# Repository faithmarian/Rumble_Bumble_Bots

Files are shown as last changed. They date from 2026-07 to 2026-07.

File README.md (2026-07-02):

# Rumble Bumble Bots

Team repository for the MTRN3100 micromouse project.

## Repository Layout

- `arduino/` - Arduino Nano sketches for sensor diagnostics, PID/IMU driving, and Week 8 driving tasks.
- `webots_week4/` - Webots worlds, robot protos, C# controller source, and map drawing utilities.
- `print/` - CAD and printable chassis/support files.
- `project/` - Project schematic images used by the team.

## Arduino Sketches

The Week 8 sketches share pin mappings and helper code in `arduino/week8_common/MTRNWeek8Common.hpp`.

Install these Arduino libraries before uploading:

- `MPU6050_light`
- `VL6180X` by Pololu

The OLED code uses `Wire` directly and does not require an extra OLED library.

## Webots Controllers

The Webots controllers are C# projects. Generated `bin/`, `obj/`, executable, DLL, and PDB outputs are intentionally ignored so the repository stays source-focused.

## Publish Notes

This repository intentionally excludes local Codex state, lecture/lab handouts, downloaded reference repositories, course PDFs, build outputs, logs, archives, and environment/secret files.

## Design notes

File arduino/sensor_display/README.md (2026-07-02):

# Sensor Display Diagnostic

Open `sensor_display.ino` in Arduino IDE and upload it to the Arduino Nano.

## What It Shows

- MPU6050 angles: X, Y, Z in degrees
- VL6180X distances: left, front, right in millimetres
- Serial Monitor debug at `115200` baud, including an I2C scan

## Libraries

Install these from Arduino Library Manager:

- `MPU6050_light` by rfetick
- `VL6180X` by Pololu

The OLED code is driven directly through `Wire`, so it does not need `U8g2`,
`Adafruit_SSD1306`, or `SSD1306Ascii`.

## Course PCB Wiring From The Schematic

- OLED SSD1306: `A4 SDA`, `A5 SCL`, `+5`, `GND`
- MPU6050: `A4 SDA`, `A5 SCL`, `+5`, `GND`
- Left VL6180X GPIO0/XSHUT: `A0`
- Front VL6180X GPIO0/XSHUT: `A2`
- Right VL6180X GPIO0/XSHUT: `A1`

The three VL6180X sensors all start at I2C address `0x29`, so the sketch turns all of them off first, then enables them one by one and changes their addresses to:

- Left: `0x54`
- Front: `0x56`
- Right: `0x55`

## If The OLED Is Still Dark

1. Check the OLED is plugged into `J13` in the right orientation.
2. Check the board has `+5V` and `GND`; the course OLED is powered from `+5V`.
3. Open Serial Monitor at `115200` and read the I2C scan.
4. If the scan does not show an OLED address, usually `0x3C`, the OLED is not electrically connected.
5. If the scan shows `0x3C` but the screen is dark, the module may not be SSD1306-compatible even though the 2025 schematic labels it as SSD1306.

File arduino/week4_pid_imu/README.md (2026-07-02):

# Week 4 PID + IMU Arduino Controller

Open `week4_pid_imu.ino` in Arduino IDE and upload to the Arduino Nano.

## What It Does

1. Calibrates the MPU6050 while the robot is stationary.
2. Drives forward 200 mm using encoder distance feedback.
3. Uses MPU6050 yaw feedback to keep the robot straight.
4. Performs four 90 degree left turns.
5. Performs four 90 degree right turns.

## Pin Mapping

This follows the UNSW MDI controller PCB and the working `micromouse1.2` code:

- Left motor/MOT1: PWM `D11`, DIR `D12`
- Right motor/MOT2: PWM `D9`, DIR `D10`
- Left encoder: A `D2`, B `D7`
- Right encoder: A `D3`, B `D8`
- MPU6050: SDA `A4`, SCL `A5`

## First Checks

- The motor convention now matches `micromouse1.2`: straight motion sends `motor1=+pwm`, `motor2=+pwm`.
- Right motor inversion is handled inside `setMotorCommand()` because motor 2 is physically mounted opposite.
- If straight motion spins in place, check the `if (motorNumber == 2) command = -command;` line.
- If a 200 mm command does not travel 200 mm, tune `WHEEL_RADIUS_MM` or `ENCODER_COUNTS_PER_REV`.
- If turning is the wrong direction, swap the signs in `setWheelPwm(turn, -turn)` inside `turnRelativeDeg`.

## Main Tuning Constants

- Straight distance: `DRIVE_DISTANCE_MM`
- Wheel radius: `WHEEL_RADIUS_MM`
- Axle track: `AXLE_TRACK_MM`
- Encoder CPR: `ENCODER_COUNTS_PER_REV`
- Straight PID: `distancePid`, `driveYawPid`, `wheelSyncPid`
- Turn PID: `turnYawPid`
- PWM caps: `DRIVE_PWM_MAX`, `TURN_PWM_MAX`

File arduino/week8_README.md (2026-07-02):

# Week 8 Arduino Sketches

These four sketches match the Week 8 simple driving assessment tasks.

## Common Hardware Assumptions

All sketches use the course PCB schematic:

- Left motor: PWM `D11`, DIR `D12`
- Right motor: PWM `D9`, DIR `D10`
- Left encoder: A `D2`, B `D7`
- Right encoder: A `D3`, B `D8`
- MPU6050: `A4 SDA`, `A5 SCL`
- OLED SSD1306: `A4 SDA`, `A5 SCL`
- Left VL6180X XSHUT: `A0`, address changed to `0x54`
- Front VL6180X XSHUT: `A2`, address changed to `0x56`
- Right VL6180X XSHUT: `A1`, address changed to `0x55`

The OLED code does not need `U8g2`. It is driven directly using `Wire`.

Install these Arduino libraries:

- `MPU6050_light`
- `VL6180X` by Pololu

## Sketches

- `week8_1_straight_tracking`: Task 3.1, drive straight slightly past the 1 m finish line using IMU heading hold.
- `week8_2_lidar_stop`: Task 3.2, front LiDAR wall following to `100 mm`.
- `week8_3_turning`: Task 3.3, right 90 degrees, then recover after external rotation.
- `week8_4_chaining`: Task 3.4, execute the marking-day command string.

## Values To Tune First

- Straight task: `STRAIGHT_DISTANCE_MM`
- Wall task: `TARGET_WALL_MM`, `WALL_TOL_MM`, PID values inside `trackWallToTarget()`
- Turning task: PID values inside `turnToYaw()` in `week8_common/MTRNWeek8Common.hpp`
- Chaining task: `COMMAND_STRING`, `CELL_DISTANCE_MM`

## OLED Display

Every sketch displays:

- `X/Y/Z`: MPU6050 angles in degrees
- `L/F/R`: left, front, right LiDAR distances in millimetres
- Top row: current task/stage

## Suggested Test Order

1. Upload `week8_1_straight_tracking` and tune straight-line PWM/PID.
2. Upload `week8_3_turning` and tune turn PID.
3. Upload `week8_2_lidar_stop` and tune wall distance control.
4. Upload `week8_4_chaining`, set the real command string, and tune `CELL_DISTANCE_MM`.

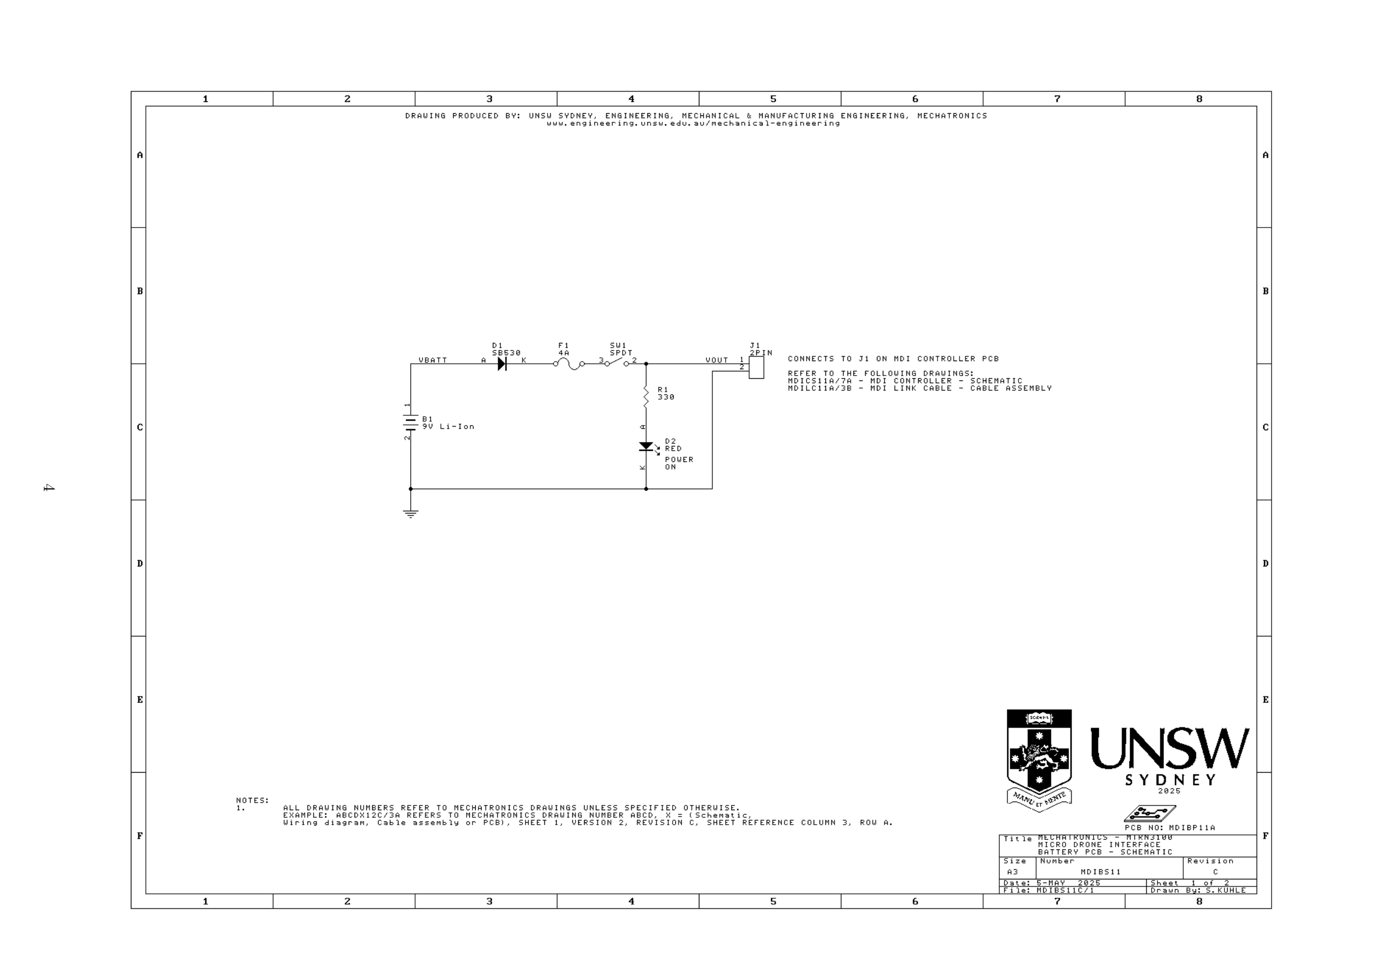
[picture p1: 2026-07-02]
project/kit_schematic-4.png

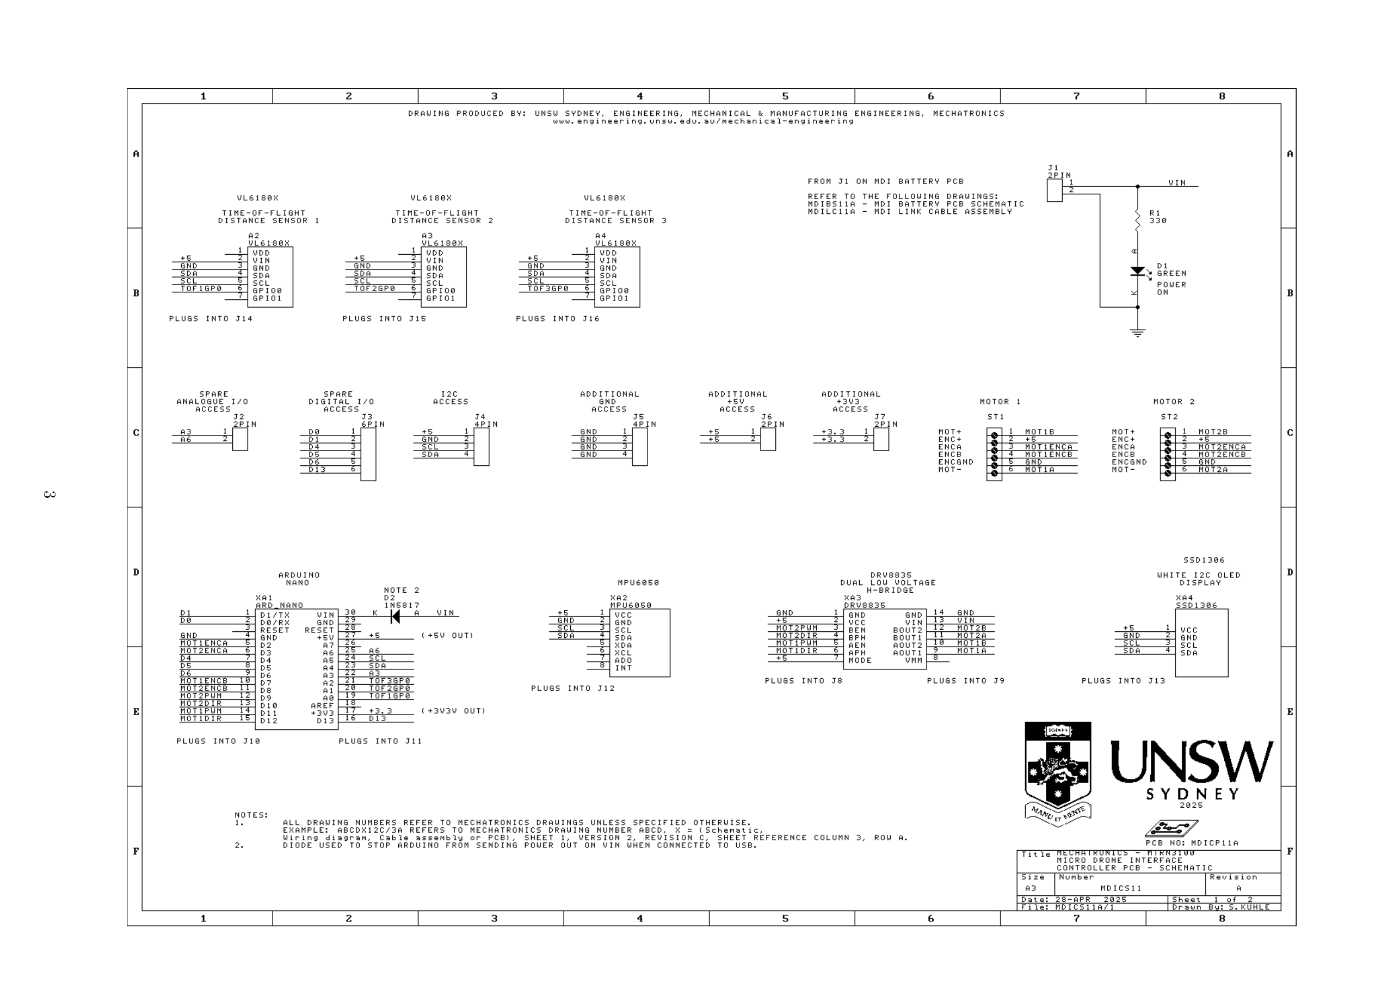
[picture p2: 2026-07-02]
project/kit_schematic-3.png

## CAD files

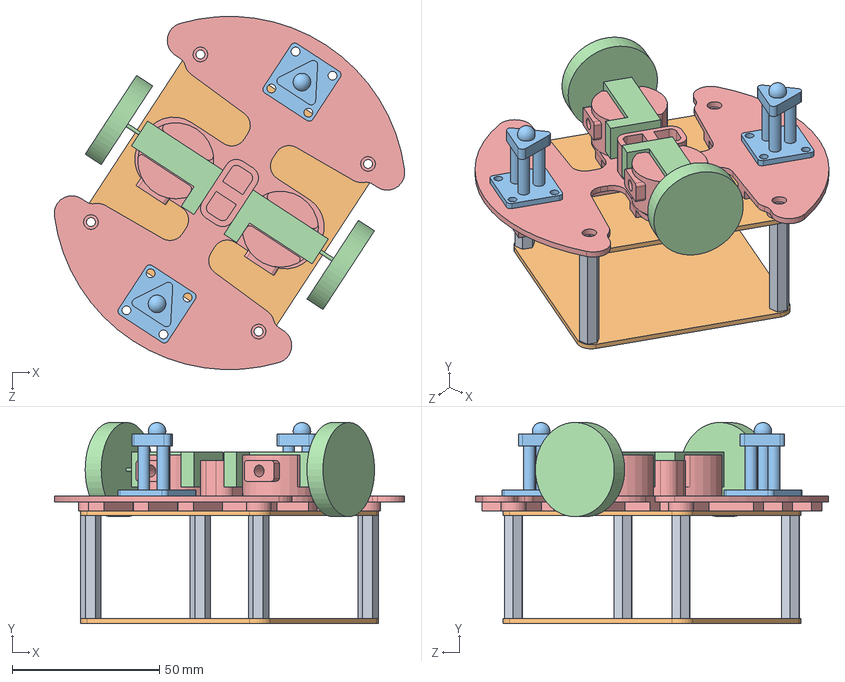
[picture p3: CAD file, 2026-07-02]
print/assume.SLDASM
119.0 x 68.3 x 119.9 mm
chassis
wheel x 2
ball_caster x 2
board x 2
support x 4

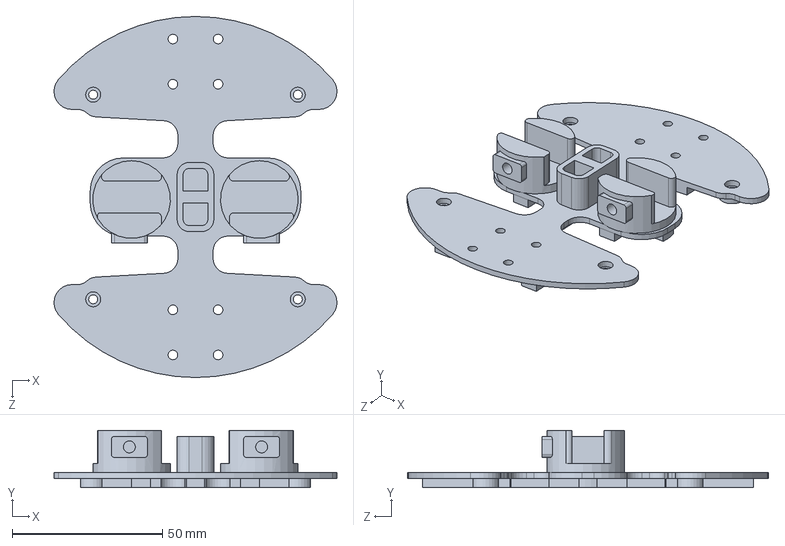
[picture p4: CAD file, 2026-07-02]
print/chassis.SLDPRT
94.1 x 19.0 x 120.0 mm

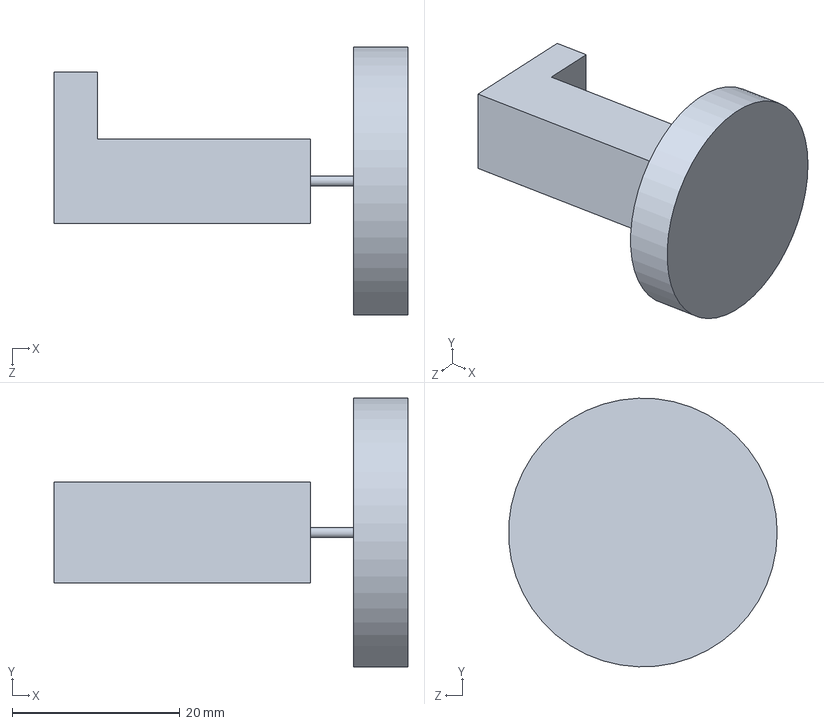
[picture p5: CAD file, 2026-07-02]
print/wheel.SLDPRT
42.2 x 32.0 x 32.0 mm

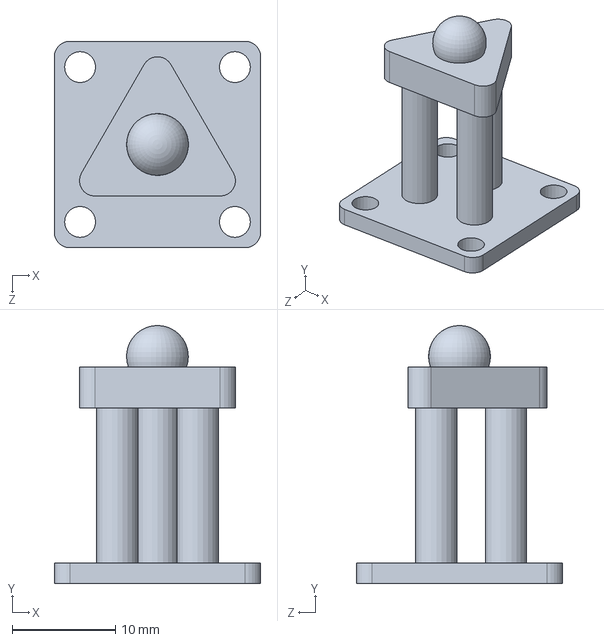
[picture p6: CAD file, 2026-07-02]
print/ball_caster.SLDPRT
20.0 x 25.0 x 20.0 mm

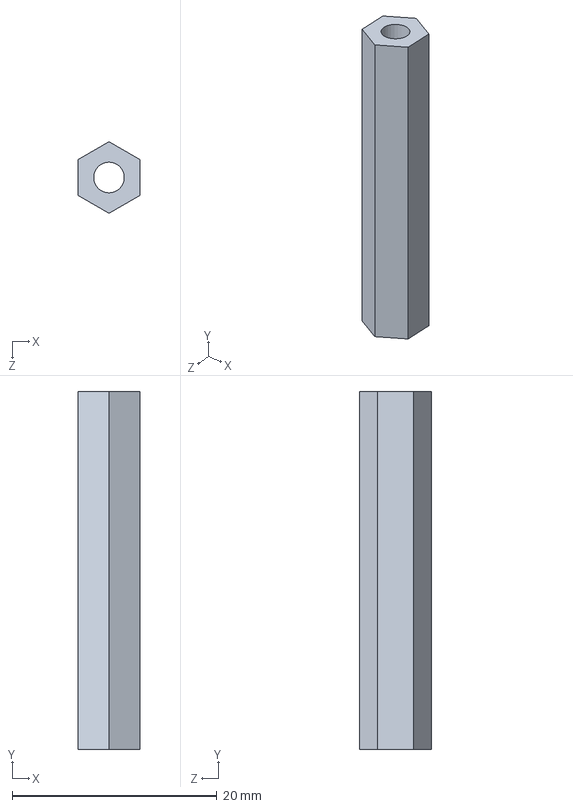
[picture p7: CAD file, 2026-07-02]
print/support.SLDPRT
6.06 x 35.0 x 7.00 mm

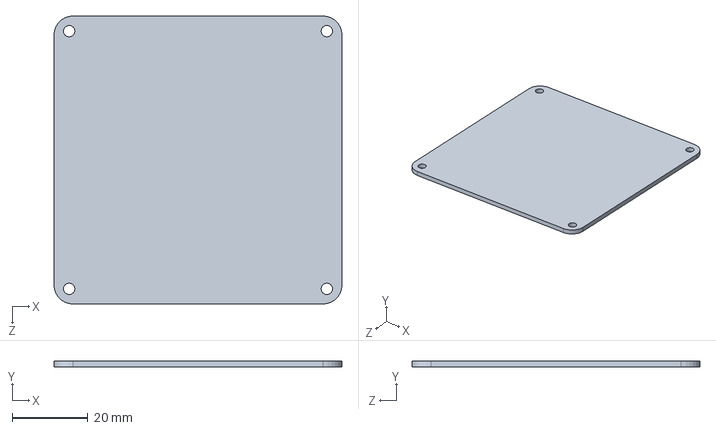
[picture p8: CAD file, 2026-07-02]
print/board.SLDPRT
76.0 x 1.65 x 76.0 mm

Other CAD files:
print/chassis.STL
print/support.STL

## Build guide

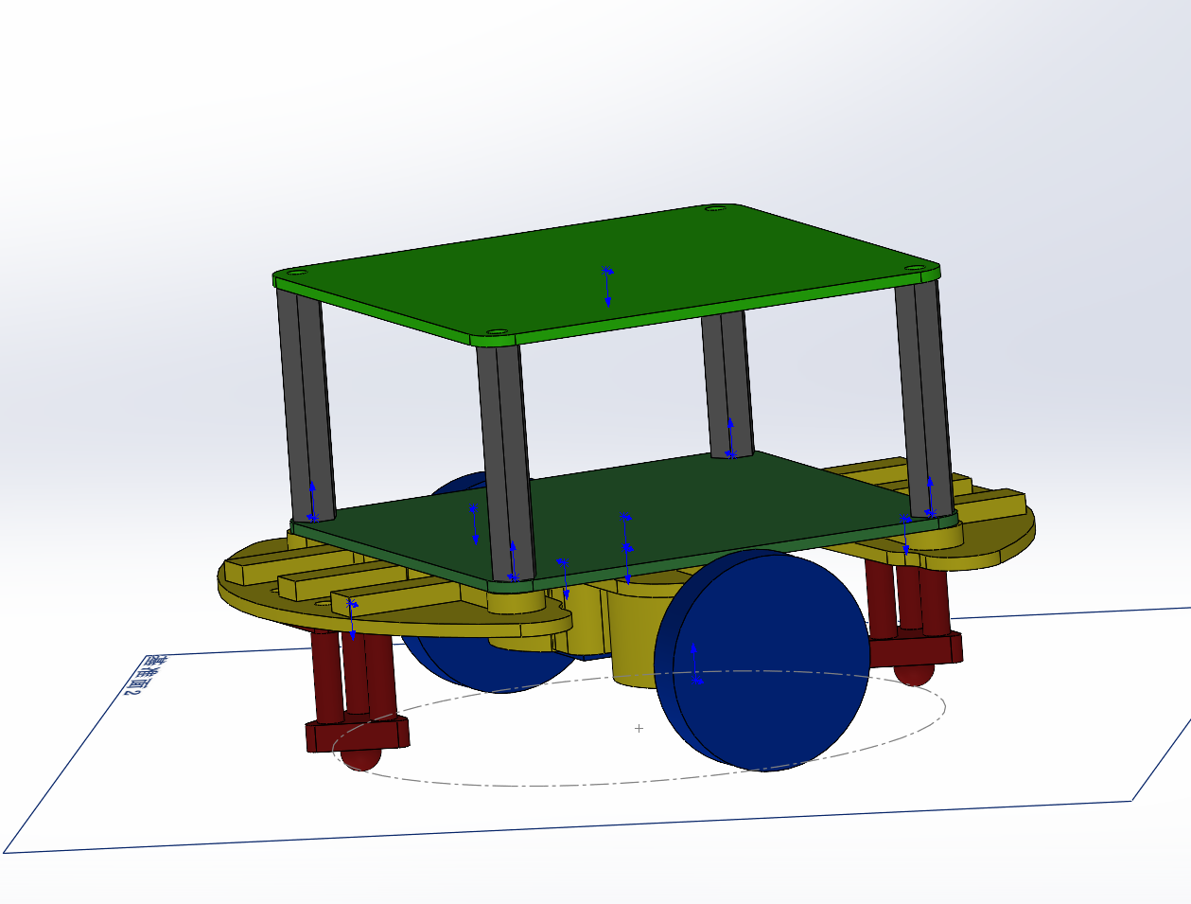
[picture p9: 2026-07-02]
print/2026-06-20 115022.png

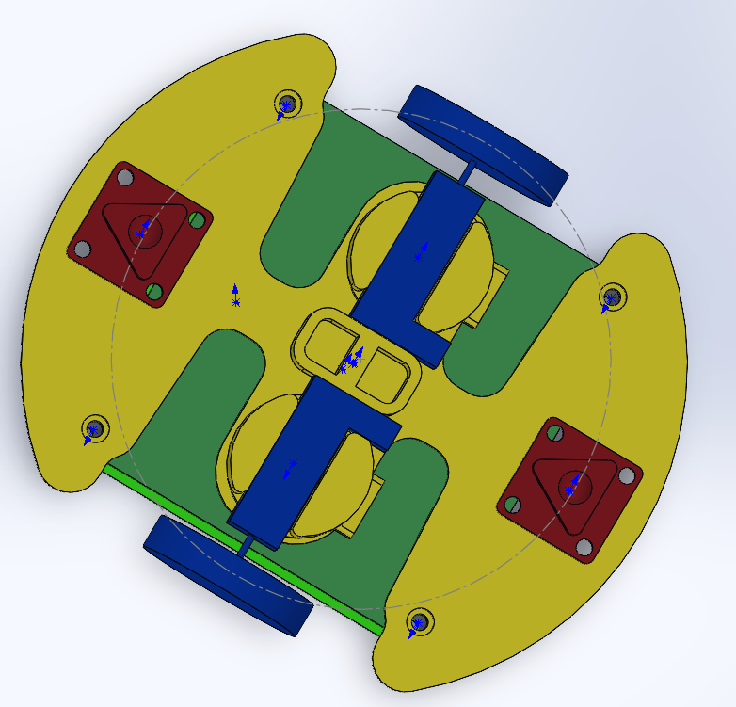
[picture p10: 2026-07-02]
print/2026-06-20 115451.png

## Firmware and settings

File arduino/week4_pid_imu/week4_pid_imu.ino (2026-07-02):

/*
  MTRN3100 Week 4 barebones movement controller.

  Sequence:
    1. Drive forward 200 mm using encoder distance PID.
    2. Hold the initial IMU yaw during the drive using yaw PID.
    3. Turn left 90 deg four times using IMU yaw PID.
    4. Turn right 90 deg four times using IMU yaw PID.

  Hardware mapping follows the UNSW MDI controller PCB and the working
  micromouse1.2 motor/encoder logic:
    Left motor  (MOT1): PWM D11, DIR D12
    Right motor (MOT2): PWM D9,  DIR D10
    Left encoder:  A D2 interrupt, B D7
    Right encoder: A D3 interrupt, B D8
    MPU6050: I2C on A4 SDA, A5 SCL

  Required Arduino library:
    MPU6050_light by rfetick
*/

#include <Arduino.h>
#include <Wire.h>
#include <MPU6050_light.h>

// ------------------------- Pin Map -------------------------
const uint8_t LEFT_ENC_A = 2;
const uint8_t LEFT_ENC_B = 7;
const uint8_t RIGHT_ENC_A = 3;
const uint8_t RIGHT_ENC_B = 8;

const uint8_t LEFT_PWM = 11;
const uint8_t LEFT_DIR = 12;
const uint8_t RIGHT_PWM = 9;
const uint8_t RIGHT_DIR = 10;

// ---------------------- Robot Geometry ---------------------
// These match the working micromouse1.2 code. Numerically this is equivalent
// to the lab04 16 mm / 700 CPR pair, but it preserves the tested convention.
const float WHEEL_RADIUS_MM = 32.0f;
const float AXLE_TRACK_MM = 90.0f;
const float ENCODER_COUNTS_PER_REV = 1400.0f;
const float MM_PER_COUNT = (2.0f * PI * WHEEL_RADIUS_MM) / ENCODER_COUNTS_PER_REV;

const float DRIVE_DISTANCE_MM = 200.0f;
const float TURN_ANGLE_DEG = 90.0f;

// -------------------- Direction Calibration ----------------
// This follows micromouse1.2:
//   motor1.setPWM(+pwm), motor2.setPWM(+pwm) drives straight.
//   motor2 is inverted inside setMotorCommand() because it is mounted opposite.
//   turn left:  motor1 +pwm, motor2 -pwm.
//   turn right: motor1 -pwm, motor2 +pwm.

// Fine trim if one side is mechanically stronger. Keep near 1.0.
const float LEFT_PWM_TRIM = 1.00f;
const float RIGHT_PWM_TRIM = 1.00f;

// ------------------------ PWM Limits -----------------------
const int DRIVE_PWM_MIN = 42;
const int DRIVE_PWM_MAX = 125;
const int TURN_PWM_MIN = 42;
const int TURN_PWM_MAX = 115;
const int CORRECTION_PWM_MAX = 45;

const float DRIVE_DONE_TOL_MM = 2.0f;
const float TURN_DONE_TOL_DEG = 1.5f;
const uint8_t DONE_STABLE_CYCLES = 10;

// -------------------------- PID ----------------------------
struct PID {
  float kp;
  float ki;
  float kd;
  float integralLimit;
  float outputLimit;
  float integral;
  float lastError;
  bool first;

  PID(float p, float i, float d, float iLimit, float oLimit)
      : kp(p), ki(i), kd(d), integralLimit(iLimit), outputLimit(oLimit),
        integral(0.0f), lastError(0.0f), first(true) {}

  void reset() {
    integral = 0.0f;
    lastError = 0.0f;
    first = true;
  }

  float update(float error, float dt) {
    if (dt <= 0.0f) {
      dt = 0.001f;
    }

    integral += error * dt;
    integral = constrain(integral, -integralLimit, integralLimit);

    float derivative = 0.0f;
    if (!first) {
      derivative = (error - lastError) / dt;
    }

    first = false;
    lastError = error;

    float output = kp * error + ki * integral + kd * derivative;
    return constrain(output, -outputLimit, outputLimit);
  }
};

// Distance error is in mm, yaw error is in deg.
PID distancePid(1.15f, 0.00f, 0.10f, 80.0f, DRIVE_PWM_MAX);
PID driveYawPid(2.30f, 0.00f, 0.10f, 45.0f, CORRECTION_PWM_MAX);
PID wheelSyncPid(0.28f, 0.00f, 0.02f, 80.0f, 18.0f);
PID turnYawPid(2.70f, 0.015f, 0.18f, 60.0f, TURN_PWM_MAX);

// ------------------------ Globals --------------------------
MPU6050 mpu(Wire);

volatile long leftTicks = 0;
volatile long rightTicks = 0;

float yawZeroDeg = 0.0f;
unsigned long lastControlMs = 0;

// ---------------------- Small Helpers ----------------------
float normalizeDeg(float angle) {
  while (angle > 180.0f) {
    angle -= 360.0f;
  }
  while (angle <= -180.0f) {
    angle += 360.0f;
  }
  return angle;
}

float yawDeg() {
  mpu.update();
  return normalizeDeg(mpu.getAngleZ() - yawZeroDeg);
}

float angleErrorDeg(float target, float current) {
  return normalizeDeg(target - current);
}

long atomicLeftTicks() {
  noInterrupts();
  long value = leftTicks;
  interrupts();
  return value;
}

long atomicRightTicks() {
  noInterrupts();
  long value = rightTicks;
  interrupts();
  return value;
}

float ticksToMm(long ticks) {
  return ticks * MM_PER_COUNT;
}

float ticksToAbsMm(long ticks) {
  return fabs(ticksToMm(ticks));
}

int applyMinPwm(float pwm, int minPwm, int maxPwm) {
  int out = (int)round(constrain(pwm, -maxPwm, maxPwm));
  if (out > 0 && out < minPwm) {
    out = minPwm;
  } else if (out < 0 && out > -minPwm) {
    out = -minPwm;
  }
  return out;
}

void setMotorRaw(uint8_t pwmPin, uint8_t dirPin, int command) {
  command = constrain(command, -255, 255);
  digitalWrite(dirPin, command >= 0 ? HIGH : LOW);
  analogWrite(pwmPin, abs(command));
}

void setMotorCommand(uint8_t motorNumber, uint8_t pwmPin, uint8_t dirPin, float command) {
  if (motorNumber == 2) {
    command = -command;
  }

  setMotorRaw(pwmPin, dirPin, (int)round(command));
}

void setWheelPwm(float motor1Command, float motor2Command) {
  setMotorCommand(1, LEFT_PWM, LEFT_DIR, motor1Command * LEFT_PWM_TRIM);
  setMotorCommand(2, RIGHT_PWM, RIGHT_DIR, motor2Command * RIGHT_PWM_TRIM);
}

void stopMotors() {
  setWheelPwm(0, 0);
}

void settleRobot(unsigned long ms = 350) {
  stopMotors();
  unsigned long start = millis();
  while (millis() - start < ms) {
    mpu.update();
    delay(5);
  }
}

// ---------------------- Encoder ISRs -----------------------
void leftEncoderISR() {
  leftTicks += digitalRead(LEFT_ENC_B) ? 1 : -1;
}

void rightEncoderISR() {
  rightTicks += digitalRead(RIGHT_ENC_B) ? 1 : -1;
}

// --------------------- Motion Primitives -------------------
void driveDistanceMm(float targetMm) {
  const long leftStart = atomicLeftTicks();
  const long rightStart = atomicRightTicks();
  const float targetYaw = yawDeg();

  distancePid.reset();
  driveYawPid.reset();
  wheelSyncPid.reset();

  uint8_t stable = 0;
  unsigned long startMs = millis();
  unsigned long lastMs = millis();
  unsigned long lastPrintMs = 0;
  float lastBase = 0.0f;
  float lastCorr = 0.0f;

  Serial.print(F("Drive target mm: "));
  Serial.println(targetMm, 1);

  while (millis() - startMs < 8000UL) {
    unsigned long now = millis();
    float dt = (now - lastMs) / 1000.0f;
    lastMs = now;

    long leftDelta = atomicLeftTicks() - leftStart;
    long rightDelta = atomicRightTicks() - rightStart;
    float leftMm = ticksToAbsMm(leftDelta);
    float rightMm = ticksToAbsMm(rightDelta);
    float travelledMm = 0.5f * (leftMm + rightMm);

    float distError = targetMm - travelledMm;
    float currentYaw = yawDeg();
    float yawError = angleErrorDeg(targetYaw, currentYaw);
    float syncError = leftMm - rightMm;

    if (abs(distError) < DRIVE_DONE_TOL_MM && abs(yawError) < 3.0f) {
      stopMotors();
      lastBase = 0.0f;
      lastCorr = 0.0f;
      stable++;
      if (stable >= DONE_STABLE_CYCLES) {
        break;
      }
    } else {
      stable = 0;

      float base = distancePid.update(distError, dt);
      base = applyMinPwm(base, DRIVE_PWM_MIN, DRIVE_PWM_MAX);

      float yawCorr = driveYawPid.update(yawError, dt);
      float syncCorr = wheelSyncPid.update(syncError, dt);
      float corr = constrain(yawCorr + syncCorr, -CORRECTION_PWM_MAX, CORRECTION_PWM_MAX);
      lastBase = base;
      lastCorr = corr;

      float leftCmd = base + corr;
      float rightCmd = base - corr;

      // Avoid driving backwards at the end of the 200 mm run; coast into the target.
      if (distError < 0.0f) {
        leftCmd = 0.0f;
        rightCmd = 0.0f;
      }

      setWheelPwm(leftCmd, rightCmd);
    }

    if (now - lastPrintMs > 120UL) {
      Serial.print(F("drive mm="));
      Serial.print(travelledMm, 1);
      Serial.print(F(" err="));
      Serial.print(distError, 1);
      Serial.print(F(" yawErr="));
      Serial.print(yawError, 2);
      Serial.print(F(" L="));
      Serial.print(leftMm, 1);
      Serial.print(F(" R="));
      Serial.print(rightMm, 1);
      Serial.print(F(" pwm="));
      Serial.print(lastBase, 0);
      Serial.print(F(" corr="));
      Serial.println(lastCorr, 1);
      lastPrintMs = now;
    }

    delay(10);
  }

  stopMotors();
  Serial.print(F("Finished drive: "));
  Serial.print(0.5f * (ticksToAbsMm(atomicLeftTicks() - leftStart) +
                       ticksToAbsMm(atomicRightTicks() - rightStart)), 1);
  Serial.print(F(" mm, yaw="));
  Serial.println(yawDeg(), 2);
}

void turnRelativeDeg(float deltaDeg) {
  const float startYaw = yawDeg();
  const float targetYaw = normalizeDeg(startYaw + deltaDeg);

  turnYawPid.reset();

  uint8_t stable = 0;
  unsigned long startMs = millis();
  unsigned long lastMs = millis();
  unsigned long lastPrintMs = 0;
  float lastTurn = 0.0f;

  Serial.print(F("Turn target deg: "));
  Serial.println(deltaDeg, 1);

  while (millis() - startMs < 6000UL) {
    unsigned long now = millis();
    float dt = (now - lastMs) / 1000.0f;
    lastMs = now;

    float currentYaw = yawDeg();
    float error = angleErrorDeg(targetYaw, currentYaw);
    if (abs(error) < TURN_DONE_TOL_DEG) {
      stopMotors();
      lastTurn = 0.0f;
      stable++;
      if (stable >= DONE_STABLE_CYCLES) {
        break;
      }
    } else {
      stable = 0;

      float turn = turnYawPid.update(error, dt);
      turn = applyMinPwm(turn, TURN_PWM_MIN, TURN_PWM_MAX);
      lastTurn = turn;

      // Positive turn command means CCW/left, matching micromouse1.2:
      // motor1 +pwm, motor2 -pwm.
      setWheelPwm(turn, -turn);
    }

    if (now - lastPrintMs > 100UL) {
      Serial.print(F("turn yaw="));
      Serial.print(currentYaw, 2);
      Serial.print(F(" err="));
      Serial.print(error, 2);
      Serial.print(F(" pwm="));
      Serial.println(lastTurn, 0);
      lastPrintMs = now;
    }

    delay(10);
  }

  stopMotors();
  Serial.print(F("Finished turn: targetDelta="));
  Serial.print(deltaDeg, 1);
  Serial.print(F(" actualDelta="));
  Serial.print(angleErrorDeg(yawDeg(), startYaw), 2);
  Serial.print(F(" finalYaw="));
  Serial.println(yawDeg(), 2);
}

// ------------------------- Setup ---------------------------
void setup() {
  Serial.begin(115200);

  pinMode(LEFT_PWM, OUTPUT);
  pinMode(LEFT_DIR, OUTPUT);
  pinMode(RIGHT_PWM, OUTPUT);
  pinMode(RIGHT_DIR, OUTPUT);
  stopMotors();

  pinMode(LEFT_ENC_A, INPUT_PULLUP);
  pinMode(LEFT_ENC_B, INPUT_PULLUP);
  pinMode(RIGHT_ENC_A, INPUT_PULLUP);
  pinMode(RIGHT_ENC_B, INPUT_PULLUP);
  attachInterrupt(digitalPinToInterrupt(LEFT_ENC_A), leftEncoderISR, RISING);
  attachInterrupt(digitalPinToInterrupt(RIGHT_ENC_A), rightEncoderISR, RISING);

  Wire.begin();
  byte status = mpu.begin();
  Serial.print(F("MPU6050 status: "));
  Serial.println(status);
  while (status != 0) {
    stopMotors();
    delay(100);
  }

  Serial.println(F("..."));
  delay(1000);
  mpu.calcOffsets(true, true);
  mpu.update();
  yawZeroDeg = mpu.getAngleZ();
  Serial.println(F("Calibration done."));

  Serial.println(F("starts in 3 seconds."));
  delay(3000);
  lastControlMs = millis();
}

// -------------------------- Loop ---------------------------
void loop() {
  Serial.println(F("=== run ==="));

  driveDistanceMm(DRIVE_DISTANCE_MM);
  settleRobot();

  for (uint8_t i = 0; i < 4; ++i) {
    Serial.print(F("Left turn "));
    Serial.print(i + 1);
    Serial.println(F("/4"));
    turnRelativeDeg(TURN_ANGLE_DEG);
    settleRobot();
  }

  for (uint8_t i = 0; i < 4; ++i) {
    Serial.print(F("Right turn "));
    Serial.print(i + 1);
    Serial.println(F("/4"));
    turnRelativeDeg(-TURN_ANGLE_DEG);
    settleRobot();
  }

  stopMotors();
  Serial.println(F("complete."));
  Serial.print(F("Final yaw relative to start: "));
  Serial.println(yawDeg(), 2);

  while (true) {
    stopMotors();
    mpu.update();
    delay(1000);
  }
}

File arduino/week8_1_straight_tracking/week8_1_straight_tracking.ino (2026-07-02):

/*
  MTRN3100 Week 8 Task 3.1 - Straight-line tracking.

  Standalone sketch. No custom .hpp library.

  Control:
    - Encoder distance PID controls forward PWM.
    - MPU6050 yaw PID keeps the robot on the starting heading.
    - OLED shows IMU X/Y/Z and LiDAR L/F/R in real time.

  If heading correction is backwards:
    - Change YAW_MOTOR_SIGN between -1 and +1.
    - This does NOT make one-way correction; it only maps IMU sign to motor sign.
*/

#include <Arduino.h>
#include <Wire.h>
#include <MPU6050_light.h>
#include <VL6180X.h>
#include <math.h>

// ------------------------- Pins -------------------------
const uint8_t LEFT_ENC_A = 2;
const uint8_t LEFT_ENC_B = 7;
const uint8_t RIGHT_ENC_A = 3;
const uint8_t RIGHT_ENC_B = 8;

const uint8_t LEFT_PWM = 11;
const uint8_t LEFT_DIR = 12;
const uint8_t RIGHT_PWM = 9;
const uint8_t RIGHT_DIR = 10;

const uint8_t LIDAR_LEFT_XSHUT = A0;
const uint8_t LIDAR_FRONT_XSHUT = A2;
const uint8_t LIDAR_RIGHT_XSHUT = A1;

// ---------------------- Assessment ----------------------
const float TARGET_DISTANCE_MM = 1050.0f;  // slightly past the 1 m finish line
const unsigned long RUN_TIMEOUT_MS = 30000UL;

// -------------------- Robot Constants -------------------
const float WHEEL_RADIUS_MM = 32.0f;
const float ENCODER_COUNTS_PER_REV = 1400.0f;
const float MM_PER_COUNT = (2.0f * PI * WHEEL_RADIUS_MM) / ENCODER_COUNTS_PER_REV;

// Your test showed positive equal commands drive backward, so forward is negative.
const float FORWARD_SIGN = -1.0f;

// Keep trims neutral; heading is corrected continuously by the yaw PID.
const float LEFT_FORWARD_TRIM = 1.00f;
const float RIGHT_FORWARD_TRIM = 1.00f;

// This only calibrates the sign between IMU yaw and motor steering.
// The PID correction itself is bidirectional: positive and negative yaw errors
// produce opposite wheel corrections.
const float YAW_MOTOR_SIGN = 1.0f;

// ------------------------ PID Tune -----------------------
// Distance PID is deliberately clamped so it cannot suddenly accelerate.
const float DIST_KP = 0.16f;
const float DIST_KI = 0.00f;
const float DIST_KD = 0.02f;

// Start conservative. If heading error decays too slowly, increase YAW_KP.
// If it snakes/oscillates, decrease YAW_KP or YAW_KD.
const float YAW_KP = 0.62f;
const float YAW_KI = 0.00f;
const float YAW_KD = 0.00f;

const int DRIVE_PWM_MIN = 38;
const int DRIVE_PWM_CRUISE = 64;
const int DRIVE_PWM_SLOW = 45;
const int DRIVE_PWM_FINAL = 34;
const int YAW_CORR_MAX = 9;
const float DRIVE_RAMP_PWM_PER_SEC = 45.0f;
const float CORR_FILTER_ALPHA = 0.12f;
const float CORR_SLEW_PWM_PER_SEC = 18.0f;
const float YAW_DEADBAND_DEG = 0.8f;
const float YAW_ERROR_LIMIT_DEG = 14.0f;

// ------------------------- Devices -----------------------
MPU6050 mpu(Wire);
VL6180X lidarLeft;
VL6180X lidarFront;
VL6180X lidarRight;

const uint8_t ADDR_LEFT = 0x54;
const uint8_t ADDR_FRONT = 0x56;
const uint8_t ADDR_RIGHT = 0x55;
const uint8_t OLED_ADDR = 0x3C;

volatile long leftTicks = 0;
volatile long rightTicks = 0;

bool imuOk = false;
bool lidarLeftOk = false;
bool lidarFrontOk = false;
bool lidarRightOk = false;

unsigned long lastDisplayMs = 0;
unsigned long lastSerialMs = 0;

// ------------------------- OLED --------------------------
// Same tiny SSD1306 text code as the diagnostic sketch, kept inside this .ino.
const uint8_t FONT_5X7[] PROGMEM = {
  0x00,0x00,0x00,0x00,0x00, 0x00,0x00,0x5F,0x00,0x00, 0x00,0x07,0x00,0x07,0x00, 0x14,0x7F,0x14,0x7F,0x14,
  0x24,0x2A,0x7F,0x2A,0x12, 0x23,0x13,0x08,0x64,0x62, 0x36,0x49,0x55,0x22,0x50, 0x00,0x05,0x03,0x00,0x00,
  0x00,0x1C,0x22,0x41,0x00, 0x00,0x41,0x22,0x1C,0x00, 0x14,0x08,0x3E,0x08,0x14, 0x08,0x08,0x3E,0x08,0x08,
  0x00,0x50,0x30,0x00,0x00, 0x08,0x08,0x08,0x08,0x08, 0x00,0x60,0x60,0x00,0x00, 0x20,0x10,0x08,0x04,0x02,
  0x3E,0x51,0x49,0x45,0x3E, 0x00,0x42,0x7F,0x40,0x00, 0x42,0x61,0x51,0x49,0x46, 0x21,0x41,0x45,0x4B,0x31,
  0x18,0x14,0x12,0x7F,0x10, 0x27,0x45,0x45,0x45,0x39, 0x3C,0x4A,0x49,0x49,0x30, 0x01,0x71,0x09,0x05,0x03,
  0x36,0x49,0x49,0x49,0x36, 0x06,0x49,0x49,0x29,0x1E, 0x00,0x36,0x36,0x00,0x00, 0x00,0x56,0x36,0x00,0x00,
  0x08,0x14,0x22,0x41,0x00, 0x14,0x14,0x14,0x14,0x14, 0x00,0x41,0x22,0x14,0x08, 0x02,0x01,0x51,0x09,0x06,
  0x32,0x49,0x79,0x41,0x3E, 0x7E,0x11,0x11,0x11,0x7E, 0x7F,0x49,0x49,0x49,0x36, 0x3E,0x41,0x41,0x41,0x22,
  0x7F,0x41,0x41,0x22,0x1C, 0x7F,0x49,0x49,0x49,0x41, 0x7F,0x09,0x09,0x09,0x01, 0x3E,0x41,0x49,0x49,0x7A,
  0x7F,0x08,0x08,0x08,0x7F, 0x00,0x41,0x7F,0x41,0x00, 0x20,0x40,0x41,0x3F,0x01, 0x7F,0x08,0x14,0x22,0x41,
  0x7F,0x40,0x40,0x40,0x40, 0x7F,0x02,0x0C,0x02,0x7F, 0x7F,0x04,0x08,0x10,0x7F, 0x3E,0x41,0x41,0x41,0x3E,
  0x7F,0x09,0x09,0x09,0x06, 0x3E,0x41,0x51,0x21,0x5E, 0x7F,0x09,0x19,0x29,0x46, 0x46,0x49,0x49,0x49,0x31,
  0x01,0x01,0x7F,0x01,0x01, 0x3F,0x40,0x40,0x40,0x3F, 0x1F,0x20,0x40,0x20,0x1F, 0x3F,0x40,0x38,0x40,0x3F,
  0x63,0x14,0x08,0x14,0x63, 0x07,0x08,0x70,0x08,0x07, 0x61,0x51,0x49,0x45,0x43, 0x00,0x7F,0x41,0x41,0x00,
  0x02,0x04,0x08,0x10,0x20, 0x00,0x41,0x41,0x7F,0x00, 0x04,0x02,0x01,0x02,0x04, 0x40,0x40,0x40,0x40,0x40,
  0x00,0x01,0x02,0x04,0x00, 0x20,0x54,0x54,0x54,0x78, 0x7F,0x48,0x44,0x44,0x38, 0x38,0x44,0x44,0x44,0x20,
  0x38,0x44,0x44,0x48,0x7F, 0x38,0x54,0x54,0x54,0x18, 0x08,0x7E,0x09,0x01,0x02, 0x0C,0x52,0x52,0x52,0x3E,
  0x7F,0x08,0x04,0x04,0x78, 0x00,0x44,0x7D,0x40,0x00, 0x20,0x40,0x44,0x3D,0x00, 0x7F,0x10,0x28,0x44,0x00,
  0x00,0x41,0x7F,0x40,0x00, 0x7C,0x04,0x18,0x04,0x78, 0x7C,0x08,0x04,0x04,0x78, 0x38,0x44,0x44,0x44,0x38,
  0x7C,0x14,0x14,0x14,0x08, 0x08,0x14,0x14,0x18,0x7C, 0x7C,0x08,0x04,0x04,0x08, 0x48,0x54,0x54,0x54,0x20,
  0x04,0x3F,0x44,0x40,0x20, 0x3C,0x40,0x40,0x20,0x7C, 0x1C,0x20,0x40,0x20,0x1C, 0x3C,0x40,0x30,0x40,0x3C,
  0x44,0x28,0x10,0x28,0x44, 0x0C,0x50,0x50,0x50,0x3C, 0x44,0x64,0x54,0x4C,0x44, 0x00,0x08,0x36,0x41,0x00,
  0x00,0x00,0x7F,0x00,0x00, 0x00,0x41,0x36,0x08,0x00, 0x10,0x08,0x08,0x10,0x08
};

class TinyOLED {
public:
  void begin() {
    const uint8_t initCommands[] = {
      0xAE,0xD5,0x80,0xA8,0x3F,0xD3,0x00,0x40,0x8D,0x14,0x20,0x00,
      0xA1,0xC8,0xDA,0x12,0x81,0xCF,0xD9,0xF1,0xDB,0x40,0xA4,0xA6,0xAF
    };
    for (uint8_t i = 0; i < sizeof(initCommands); ++i) command(initCommands[i]);
    clear();
  }

  void clear() {
    for (uint8_t row = 0; row < 8; ++row) clearRow(row);
  }

  void clearRow(uint8_t row) {
    setCursor(0, row);
    for (uint8_t i = 0; i < 128; ++i) data(0);
  }

  void drawString(uint8_t col, uint8_t row, const char *s) {
    setCursor(col * 8, row);
    while (*s && col < 16) {
      drawChar(*s++);
      col++;
    }
  }

  void drawLine(uint8_t row, const char *s) {
    clearRow(row);
    drawString(0, row, s);
  }
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
